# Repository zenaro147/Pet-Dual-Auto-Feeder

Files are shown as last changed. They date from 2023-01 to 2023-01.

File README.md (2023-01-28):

# Alimentador Automático para Pets
Sim, mais um projeto de alimentador automático. Porém o diferencial dele é que é possível alimentar 2 potes com o mesmo alimentador. Muito útil caso tenha 2 bichinhos que comem em potes separados.

O projeto é alimentado primariamente por uma fonte de energia de 12v e como fonte alternativa,caso ocorra falta de energia, uma segunda fonte de energia entre 9v e 12v.

## Componentes:
* Arduino Mega2560
* Modulo RTC DS1307
* Servo motor SG90
* Motor de Passo 28BYJ-48 + driver controle ULN2003 (é possível usar um motor DC juntamente com um Rele, porém é necessário adaptar o código)
* Display LCD 16x2 I2C
* 3 botões (push button/chave tactil)
* Módulo Conversor Step Down 6/24VDC Para 5V 3A
* Buzzer 5v Ativo (opcional)
* Rele T73 DC-12V 10A (Caso queira colocar uma fonte de energia alternativa)

## Montagem
**I2C LCD**
* VCC >> 5v
* GND >> GND
* SDA >> Pino 20
* SCL >> Pino 21

**RTC DS1307**
* VCC >> 5v
* GND >> GND
* SDA >> Pino 20
* SCL >> Pino 21 

**Buzzer**
* Negativo >> GND
* Positivo >> Pino 24

**Servo Motor**
* Fio Laranja >> Pino 9
* Fio Vermelho >> 5v
* Fio Marrom >> GND

**Motor de passo**
* In1 >> Pino 24
* In2 >> Pino 5
* In3 >> Pino 6
* In4 >> Pino 7

**3 Push Buttons (Chave Tactil)**
* GND e Pinos 28, 30, 32

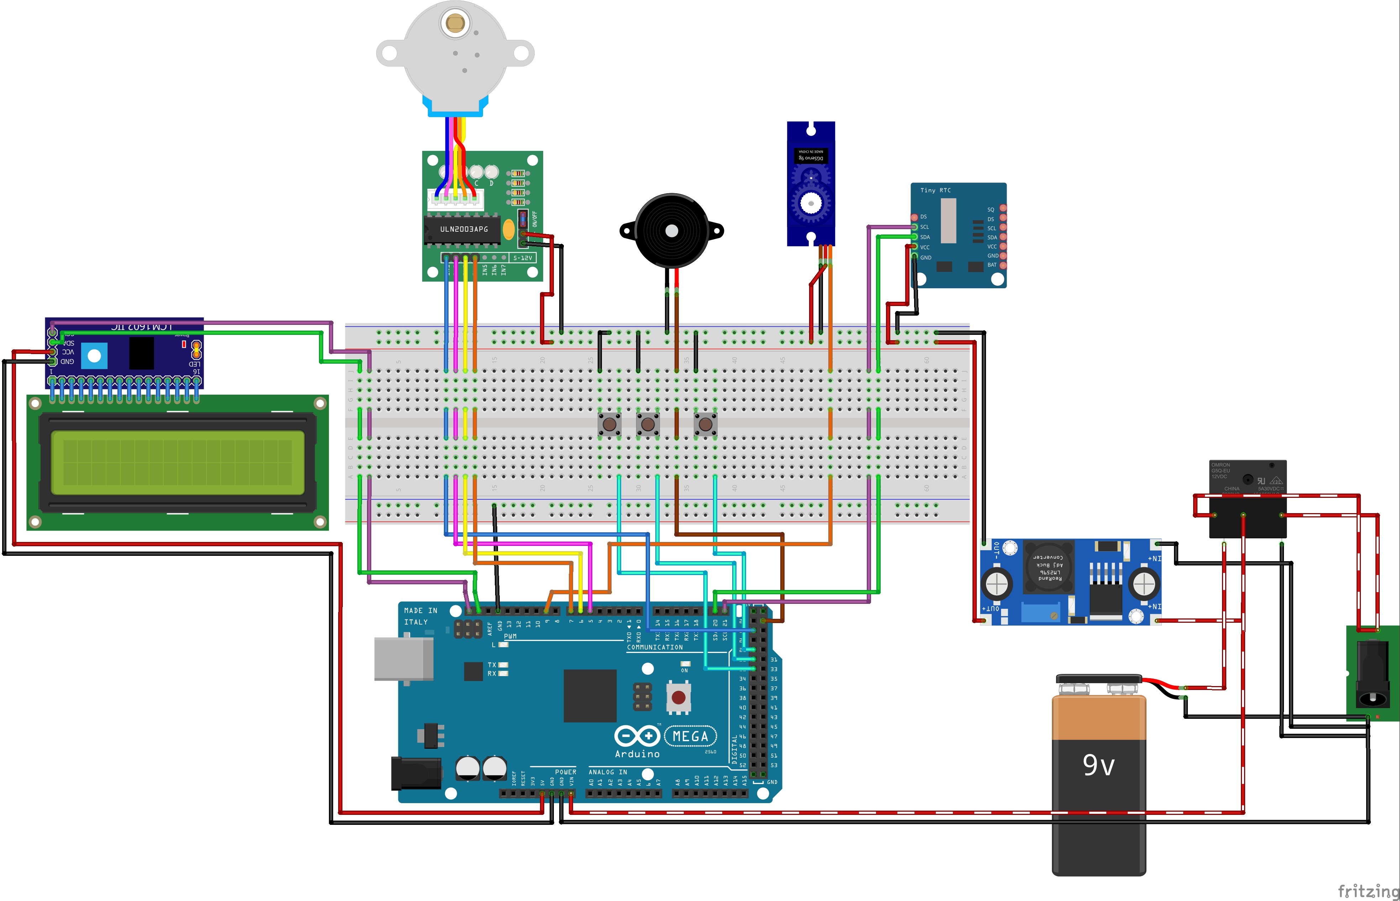
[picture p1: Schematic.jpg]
Esquema de ligação


### To do
* ~~⚠Correção de bug onde o arduino trava após alguns minutos (mais ou menos uns 10min rodando direto)~~
* Possível otimização para executar usando um Arduino Uno? (O projeto começou a ser desenvolvido nele, porém alegou falta de memória, o que interfiria nas mensagens no LCD)
* Desenho completo do chassi para montagem

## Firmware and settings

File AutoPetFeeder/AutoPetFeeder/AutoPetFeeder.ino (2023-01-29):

////////////////////////////////////////////////////////////////////////////////
// Alimentador PET v1.0 com capacidade para alimentar 2 potes
//
// Requisitos:
// Arduino Mega2560
// Modulo RTC DS1307
// Servo motor SG90
// Motor de Passo 28BYJ-48 + driver controle ULN2003 
// Display LCD 16x2 I2C
// 3 botões (push button/chave tactil)
// Módulo Conversor Step Down 6/24VDC Para 5V 3A
// Buzzer 5v Ativo (opcional)
// Rele T73 DC-12V 10A (Caso queira colocar uma fonte de energia alternativa)
//
////////////////////////////////////////////////////////////////////////////////
#include "config.h"

//Bibliotecas do LCD
#include <Wire.h>
#include <LiquidCrystal_I2C.h>

//Biblioteca Servo
#include <Servo.h>

//Biblioteca RTC
#include "RTClib.h"

//Biblioteca EEPROM
#include <EEPROM.h>

//Biblioteca Motor de passo
#include <Stepper.h>

#include "LCD_MenuOpcoes.h"

////////////////////////////////////////////////////////////////////////////////
// VARIAVEIS INTERNAS DO PROGRMAA
////////////////////////////////////////////////////////////////////////////////
int servoPos = 0;
Servo mServo;

//Define LCD I2C
LiquidCrystal_I2C lcd(enderecoLCD, LCDqtdeColunas, LCDqtdeLinhas);
bool boolTelaLigada = true;
volatile unsigned long millisLCD = 0;

//Define RTC
RTC_DS1307 rtc;

//Define Motor de passo
#ifdef InverterIN2IN3
Stepper mp(passosPorVolta, PinoIN1,PinoIN3,PinoIN2,PinoIN4); //Caso tenha probemas com o motor, inverter a posição do 9 e 10
#else
Stepper mp(passosPorVolta, PinoIN1,PinoIN2,PinoIN3,PinoIN4); //Caso tenha probemas com o motor, inverter a posição do 9 e 10
#endif

//Variavel para "travar" o Menu
bool CheckEditandoItem = false;

//Tempo em segundos que o motor ficará ligado jogando comida
int tempoAlimentadorLigado[3] = {5,5,5}; //Timer1, Timer2, Manual

//Variavel que controla se o Timer1 e/ou Timer2 está ativado
int acionarTimerAlimentador[2] = {0,0}; //Timer1, Timer2

//Hora e Minuto dos timers
int dadosTimer[] = {0,0,1,0}; //horaTimer1, minutoTimer1, horaTimer2, minutoTimer2

//Variavel que controla se o Timer1 e/ou Timer2 ja foi acionado no dia
bool timerJaAcionou[2] = {false,false}; //Timer1, Timer2

//Data e Hora do RTC
volatile uint16_t dadosRTC[] = {0,0,1,1,2023}; //Hora, Minuto, Dia, Mes, Ano
volatile unsigned long millisRTC = 0;

////////////////////////////////////////////////////////////////////////////////
// FUNÇÃO SETUP DO PROGRAMA
////////////////////////////////////////////////////////////////////////////////
void(* resetFunc) (void) = 0;//declare reset function at address 0

void setup(){
  Serial.begin(115200);

  Serial.println("//////////////////////////////////////////");
  Serial.println("Alimentador PET v1.0");
  Serial.println("//////////////////////////////////////////");
  Serial.println("Iniciando programa...");
  delay (1000);

  Serial.println("Iniciando LCD...");
  SetupLCD();
  
  Serial.println("Iniciando servo...");
  SetupServo();

  Serial.println("Iniciando motor de passo...");
  mp.setSpeed(velocidadeMotor);

  Serial.print("Lendo configurações salvas...");
  if(LeMemoria()){
    Serial.println("Dados carregados!");
  }else{    
    Serial.println("Não existem valores dados a serem carregados!");
  }

  Serial.print("Iniciando relógio...");
  SetupRTC();

  Serial.println("Iniciando demais pinos e buzzer...");
  // Define pino dos menus
  pinMode(BtnMenuEsquerda, INPUT_PULLUP);
  pinMode(BtnMenuDireita, INPUT_PULLUP);
  pinMode(BtnMenuSelect, INPUT_PULLUP);  
  
  //Pino do Buzzer
  pinMode(BuzzerPin, OUTPUT);
  tone(BuzzerPin, BuzzerNote, 250);

  //Valida gatilhos a serem disparados baseado no horario
  Serial.println("Atualizando gatilhos...");
  ValidaGatilhos();
  
  millisLCD = millis();
  millisRTC = millisLCD;
  Serial.println("Programa iniciado!");
  Serial.println("//////////////////////////////////////////");

  mServo.detach();
  
  //Imprime Data e Hora no display
  char buffLCD[18] = {0};
  sprintf(buffLCD, "%02d/%02d/%4d %2d:%02d", dadosRTC[2], dadosRTC[3],dadosRTC[4],dadosRTC[0],dadosRTC[1]);
  lcd.setCursor(0,0);
  lcd.print(buffLCD);
}

void SetupServo(){
  mServo.attach(ServoPin);
  mServo.write(AnguloPadraoServo);
}

void SetupLCD(){
  lcd.init();
  lcd.backlight();
  lcd.setCursor(0, 0);
  lcd.print("Alimentador Pet");
  lcd.setCursor(0, 1);
  lcd.print("  Iniciando...");
  ImprimeSetasMenu();
  lcd.setCursor(1,1);
  lcd.print(MainMenuOptions[0]);
}

void SetupRTC(){
  if (!rtc.begin()) {
    Serial.println("Erro ao iniciar relógio!");
  }else{   
    AtualizaVarsRelogio();
    Serial.print("Sucesso! Data/Hora Atual: ");      
    char buffLCD[20];
    sprintf(buffLCD, "%02d/%02d/%4d - %2d:%02d", dadosRTC[2], dadosRTC[3],dadosRTC[4],dadosRTC[0],dadosRTC[1]);
    Serial.println(buffLCD);
  }
  if (!rtc.isrunning()) {
    Serial.println("RTC precisa ser configurado!");
    AjustaRelogio();
  }
}

////////////////////////////////////////////////////////////////////////////////
// FUNÇÃO LOOP DO PROGRAMA
////////////////////////////////////////////////////////////////////////////////

void loop(){
  if(!CheckProgHorarioAccess && !CheckConfigRelogioAccess){
    SincronizaRelogio();
  }

  if (digitalRead(BtnMenuEsquerda) == estadoBotao || digitalRead(BtnMenuDireita) == estadoBotao || digitalRead(BtnMenuSelect) == estadoBotao){
    if(!boolTelaLigada){
      lcd.display();
      lcd.backlight();
      boolTelaLigada=true;
      MostraDataHoraDisplay();
    }
    millisLCD = millis();
    tone(BuzzerPin, BuzzerNote, 10);
    ProcessaMenu();
    delay(250); 
  }else{
    //Desliga o LCD após um certo periodo
    if(boolTelaLigada){
      if((unsigned long)(millis() - millisLCD)/1000 >= timeoutLCD){
        lcd.noDisplay();
        lcd.noBacklight();
        boolTelaLigada=false;
        millisLCD=0;
      }
    }
    
    //Aciona o alimentador no horario determinado
    if(acionarTimerAlimentador[0] == 1 && !timerJaAcionou[0] && dadosRTC[0] == dadosTimer[0] && dadosRTC[1] == dadosTimer[1]){
      timerJaAcionou[0] = true;
      ExecAlimentar(tempoAlimentadorLigado[0]);
    }
    if(acionarTimerAlimentador[1] ==  1&& !timerJaAcionou[1] && dadosRTC[0] == dadosTimer[2] && dadosRTC[1] == dadosTimer[3]){
      timerJaAcionou[1] = true;
      ExecAlimentar(tempoAlimentadorLigado[1]);
    }
  }

  // Diagnostics Console
  while (Serial.available() > 0){
    switch (Serial.read()){
      case '1':
        Serial.print("Gatilho 1: ");
        Serial.print(acionarTimerAlimentador[0]);
        Serial.print(" - ");
        Serial.print(timerJaAcionou[0]);
        Serial.print("/");
        Serial.print(dadosTimer[0]);
        Serial.print(":");
        Serial.println(dadosTimer[1]);
        
        Serial.print("Gatilho 2: ");
        Serial.print(acionarTimerAlimentador[1]);
        Serial.print(" - ");
        Serial.print(timerJaAcionou[1]);
        Serial.print("/");
        Serial.print(dadosTimer[2]);
        Serial.print(":");
        Serial.println(dadosTimer[3]);
        break;
        
      case '2':
        Serial.print("Data/Hora Atual: ");
        Serial.print(dadosRTC[2]);
        Serial.print("/");
        Serial.print(dadosRTC[3]);
        Serial.print("/");
        Serial.print(dadosRTC[4]);
        Serial.print(" - ");
        Serial.print(dadosRTC[0]);
        Serial.print(":");
        Serial.println(dadosRTC[1]);
        break;
    }
  }
  
}

void ExecAlimentar(short tempoLigado){
  SetupServo();
  
  lcd.setCursor(0, 1);
  lcd.print("Preparando pote1");
  Serial.println("Alimentando pote 1...");  
  //Vira o Servo para alimentar o primeiro pote
  tone(BuzzerPin, BuzzerNote, 500);
  for (servoPos = AnguloPadraoServo; servoPos <= AnguloPadraoServo+AnguloServo; servoPos += 1) {
    mServo.write(servoPos);
    delay(10);
  }  
  //Alimenta o pote
  unsigned long millisMotor = millis();
  while(millis() - millisMotor <= tempoLigado*1000){
    mp.step(1);
  } 

  lcd.setCursor(0, 1);
  lcd.print("Preparando pote2");
  Serial.println("Alimentando pote 2...");  
  //Vira o Servo para alimentar o segundo pote
  for (servoPos = AnguloPadraoServo+AnguloServo; servoPos >= AnguloPadraoServo-AnguloServo; servoPos -= 1) {
    mServo.write(servoPos);
    delay(10);
  }  
  //Alimenta o pote
  millisMotor = millis();  
  while(millis() - millisMotor <= tempoLigado*1000){
    mp.step(1);
  }
  
  lcd.setCursor(0, 1);
  lcd.print(" Finalizando... ");
  Serial.println("Finalizando...");  
  //Reseta o Servo
  for (servoPos = AnguloPadraoServo-AnguloServo; servoPos <= AnguloPadraoServo; servoPos += 1) {
    mServo.write(servoPos);
    delay(10);
  }

  mServo.detach();
  
  tone(BuzzerPin, BuzzerNote, 250);
  delay(500);
  tone(BuzzerPin, BuzzerNote, 250);

  lcd.setCursor(0, 1);
  lcd.print("   Concluido!   ");
  Serial.println("Ração colocada!");
  delay(2000);
  ResetaMenu();
}



  

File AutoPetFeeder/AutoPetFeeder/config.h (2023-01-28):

////////////////////////////////////////////////////////////////////////////////
// DEFINIÇÃO DE VARIAVEIS E PINOS DO PROGRAMA
////////////////////////////////////////////////////////////////////////////////
//#define DEBUG_MODE              //HABILITA OPÇÕES DE DEBUG NO SERIAL PARA MONITORAMENTO

//Botões do menu
#define BtnMenuEsquerda 32        //Define botão "Esquerda" do Menu
#define BtnMenuDireita 30         //Define botão "Direita" do Menu
#define BtnMenuSelect 28          //Define botão "Selecionar" do Menu
#define estadoBotao LOW           //Define estado que o botão tem que estar para ser reconhecido (Padrão: LOW)

//Servo motor
#define ServoPin 9                //Pino que o Servo Motor está conectado (precisa ser OU pino 9 OU pino 10. Apenas esses funcionam)
#define AnguloServo 45            //Servo irá virar 45 graus para poder bloquear uma saida e despejar comida em um pote
#define AnguloPadraoServo 90      //Angulo padrão do Servo quando ele estiver parado. Definir angulo entre 40 e 135.

//Tela LCD
#define enderecoLCD 0x27          //Pode ser necessário mudar esse valor. Esse link contem um scanner I2C que pode ajudar a localizar o valor do seu LCD 
#define LCDqtdeColunas 16         //Pode ser necessário mudar esse valor. Esse link contem um scanner I2C que pode ajudar a localizar o valor do seu LCD 
#define LCDqtdeLinhas 2           // Pode ser necessário mudar esse valor. Esse link contem um scanner I2C que pode ajudar a localizar o valor do seu LCD 
#define timeoutLCD 10             //Tempo máximo que a tela ficará ligada

//Módulo RTC
#define intervaloAttRelogio 5     //Intervalo em segundos da atualização do relogio

//Buzzer
#define BuzzerPin 23              //Pino usado pelo Buzzer
#define BuzzerNote 698            //Nota que buzzer irá fazer

//Motor de Passo
#define passosPorVolta 32         //Passos por volta do motor de passo (Padrão: 32)
#define velocidadeMotor 500       //Velocidade do motor de passo (Padrão: 500)
#define PinoIN1 24                //Pino Digital que a entrada IN1 foi ligada
#define PinoIN2 5                 //Pino Digital que a entrada IN2 foi ligada
#define PinoIN3 6                 //Pino Digital que a entrada IN3 foi ligada
#define PinoIN4 7                 //Pino Digital que a entrada IN4 foi ligada
#define InverterIN2IN3            //Em alguns casos, pode ser necessário ativar essa linha para o motor funcionar

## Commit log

2023-01-23 Atualizado para Arduino Mega
2023-01-23 Correção de bugs.
2023-01-23 Apartado definições manuais para um unico arquivo!
2023-01-27 Initial Schematic
    [Schematic.fzz]
2023-01-28 Primeira versão previamente funcional
    [Schematic.fzz]
2023-01-28 Correção na validação dos Timers
